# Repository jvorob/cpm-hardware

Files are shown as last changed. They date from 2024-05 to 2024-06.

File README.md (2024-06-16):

# cpm-hardware

This repo contains the design files for the custom PCB used in my Cathodic Protection Monitoring project.
These were developed in KiCad 8.
(see [main repo](https://github.com/jvorob/cpm-firmware) for more details)

`cpm_proj/` Contains the mk1 board used as of 2024.06.16, a 100x100mm 2-layer PCB.

`cpm_mk2/` is the start of a planned second version, if I get around to miniaturizing and deploying it.

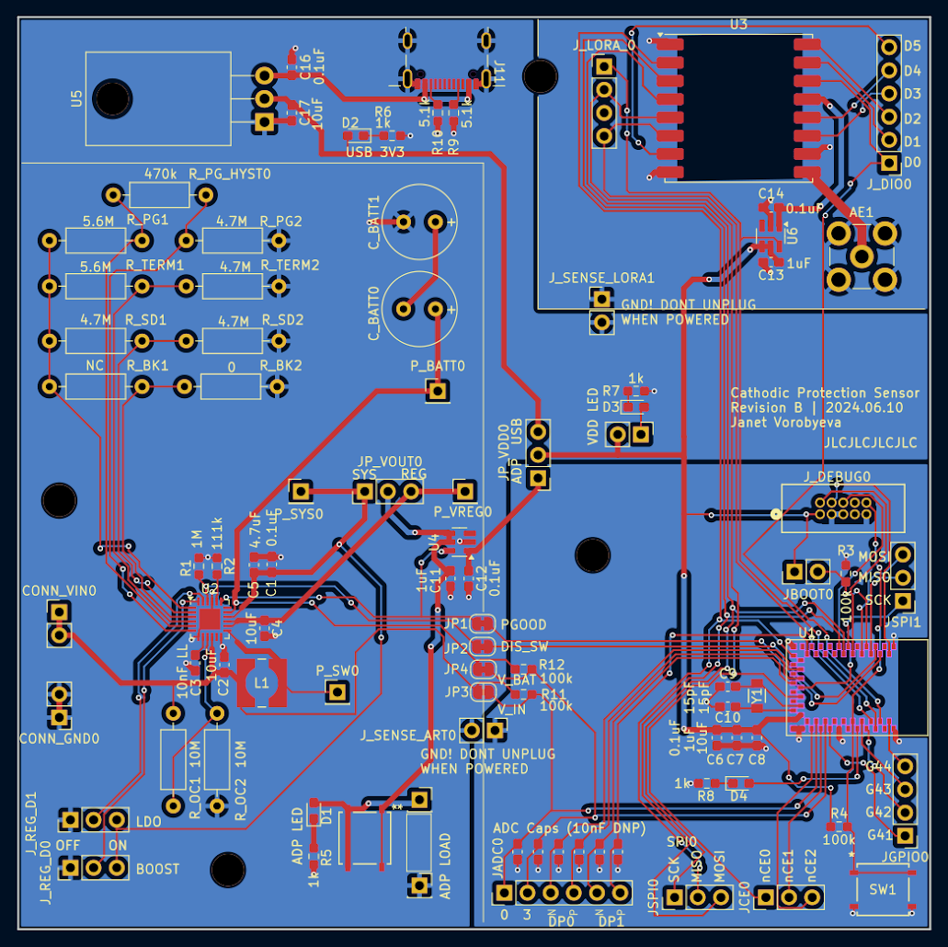
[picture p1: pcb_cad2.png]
Image of the mk1 pcb design


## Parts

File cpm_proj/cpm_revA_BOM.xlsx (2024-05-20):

Reference | Type | Value | Datasheet | Footprint | Qty | In Stock? | Order | DNP |  | PN | Digikey PN
C9,C10 | Passive – Capacitor | 15pF | ~ | Capacitor_SMD:C_0603_1608Metric_Pad1.08x0.95mm_HandSolder | 2 | ~30
C15,C18,C19,C20,C21,C22 | Passive – Capacitor | 1nF | ~ | Capacitor_SMD:C_0603_1608Metric_Pad1.08x0.95mm_HandSolder | 6 | ~30 |  | DNP
C1,C6,C12,C14,C16 | Passive – Capacitor | 0.1uF | ~ | Capacitor_SMD:C_0603_1608Metric_Pad1.08x0.95mm_HandSolder | 5 | ~20
C7,C11,C13 | Passive – Capacitor | 1uF | ~ | Capacitor_SMD:C_0603_1608Metric_Pad1.08x0.95mm_HandSolder | 3 | 30
C5 | Passive – Capacitor | 4.7uF | ~ | Capacitor_SMD:C_0603_1608Metric_Pad1.08x0.95mm_HandSolder | 1 | 0 | 50 |  | Jelly | C1608X5R1E475K080AC | 445-9050-1-ND
C2,C4,C8,C17 | Passive – Capacitor | 10uF | ~ | Capacitor_SMD:C_0603_1608Metric_Pad1.08x0.95mm_HandSolder | 4 | ~5
R11,R12,R3,R4 | Passive – Resistor | 100k | ~ | Resistor_SMD:R_0603_1608Metric_Pad0.98x0.95mm_HandSolder | 4 | ~20
R2 | Passive – Resistor | 111k | ~ | Resistor_SMD:R_0603_1608Metric_Pad0.98x0.95mm_HandSolder | 1 | ~20
R5,R6,R7,R8 | Passive – Resistor | 1k | ~ | Resistor_SMD:R_0603_1608Metric_Pad0.98x0.95mm_HandSolder | 4 | ~20 | 1000 |  | Jelly | RMCF0603FG1K00 | RMCF0603FG1K00CT-ND
R9,R10 | Passive – Resistor | 5.1k | ~ | Resistor_SMD:R_0603_1608Metric_Pad0.98x0.95mm_HandSolder | 2 | ~20
R1 | Passive – Resistor | 1M | ~ | Resistor_SMD:R_0603_1608Metric_Pad0.98x0.95mm_HandSolder | 1 | 0 | 50? |  | Jelly | RMCF0603FG1M00 | RMCF0603FG1M00CT-ND
R_OC1,R_OC2 | Passive – Resistor | 10M | ~ | Resistor_THT:R_Axial_DIN0207_L6.3mm_D2.5mm_P10.16mm_Horizontal | 2 | 8 | 0
R_PG1,R_TERM1 | Passive – Resistor | 5.6M | ~ | Resistor_THT:R_Axial_DIN0207_L6.3mm_D2.5mm_P10.16mm_Horizontal | 2 | 0 | 10 |  |  | CF14JT5M60 | CF14JT5M60CT-ND
R_PG2,R_SD1,R_SD2,R_TERM2 | Passive – Resistor | 4.7M | ~ | Resistor_THT:R_Axial_DIN0207_L6.3mm_D2.5mm_P10.16mm_Horizontal | 4 | 10 | 0
R_PG_HYST0 | Passive – Resistor | 470k | ~ | Resistor_THT:R_Axial_DIN0207_L6.3mm_D2.5mm_P10.16mm_Horizontal | 1 | 5 | 0
R_BK1 | N/A | NC | ~ | Resistor_THT:R_Axial_DIN0207_L6.3mm_D2.5mm_P10.16mm_Horizontal | 1 | N/A |  | DNP
R_BK2 | N/A | 0 | ~ | Resistor_THT:R_Axial_DIN0207_L6.3mm_D2.5mm_P10.16mm_Horizontal | 1 | N/A
C3 | Passive – Special | 10nF LL | https://www.digikey.com/en/products/detail/murata-electronics/GRT1885C1E103JA02J/13904823 | Capacitor_SMD:C_0603_1608Metric_Pad1.08x0.95mm_HandSolder | 1 | 0 | 10 |  |  | GRT1885C1E103JA02J | 490-GRT1885C1E103JA02JCT-ND
C_BATT0,C_BATT1 | Supercapacitor | 1F 2.7V | https://www.digikey.com/en/products/detail/cornell-dubilier-knowles/DGH105Q2R7/7387508 | Capacitor_THT:C_Radial_D8.0mm_H11.5mm_P3.50mm | 2 | 2 | 10 |  |  | DGH105Q2R7 | 338-DGH105Q2R7-ND
D1,D2,D3,D4 | Led | LED GN? | ~ | LED_SMD:LED_0603_1608Metric_Pad1.05x0.95mm_HandSolder | 4 | 0 | 20? |  | Jelly | SML-D12P8WT86 | 846-SML-D12P8WT86CT-ND
SW1, SW_ADP_LED0 | Switch | PTS526 Switch | https://www.digikey.com/en/products/detail/c-k/PTS526-SK15-SMTR2-LFS/10056626 | 0JV_CPM_Footprints:SMT_FS_PTS526 | 2 |  | 25 |  | Jelly | PTS526 SK15 SMTR2 LFS | CKN12221-1-ND
U1 | IC | Sparkfun Artemis | https://cdn.sparkfun.com/assets/learn_tutorials/9/0/9/Artemis_Integration_Guide.pdf | 0JV_CPM_Footprints:Sparkfun Artemis | 1 | 0 | 10? |  | Restock | WRL-15484 | 1568-WRL-15484CT-ND | 30c cheaper on sparkfun? | https://www.sparkfun.com/products/15484
U2 | IC | ADP5091 | https://www.analog.com/media/en/technical-documentation/data-sheets/ADP5091-5092.pdf | Package_CSP:LFCSP-24-1EP_4x4mm_P0.5mm_EP2.3x2.3mm | 1 | ??? | 2? |  |  | ADP5091ACPZ-1-R7 | 505-ADP5091ACPZ-1-R7CT-ND
U3 | IC | RFM95W-915S2 | https://www.hoperf.com/data/upload/portal/20181127/5bfcbea20e9ef.pdf | RF_Module:HOPERF_RFM9XW_SMD | 1 | ~2 | 0
U4,U6 | IC | TPS22860 | https://www.ti.com/lit/ds/symlink/tps22860.pdf | Package_TO_SOT_SMD:SOT-23-6 | 2 | 0 | 5? |  |  | TPS22860DBVR | 296-43982-1-ND
U5 | IC | LD1117AV33_TO220 | https://www.st.com/content/ccc/resource/technical/document/datasheet/a5/c3/3f/c9/2b/15/40/49/CD00002116.pdf/files/CD00002116.pdf/jcr:content/translations/en.C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 | Package_TO_SOT_THT:TO-220-3_Horizontal_TabDown | 1 | TRUE | 0
Y1 | Crystal | 32.768kHz | https://www.digikey.com/en/products/detail/ecs-inc/ECS-327-12-5-34B-TR/1693557 | 0JV_CPM_Footprints:XTAL_ECS-31B_ECS | 1 | 0 | 10 |  |  | ECS-.327-12.5-34B-TR | XC1617CT-ND
L1 | Inductor | 22uH | https://www.digikey.com/en/products/detail/w%C3%BCrth-elektronik/744042220/2931638 | 0JV_CPM_Footprints:IND_4818-WE-TPC_WRE | 1 | 0 | 10? |  |  | 744042220 | 732-3657-1-ND
J11 | Connector | USB_C_Receptacle_USB2.0 | https://www.digikey.com/en/products/detail/gct/USB4105-GF-A/11198441 | 0JV_CPM_Footprints:USB4105-GF-A | 1 | 0 | 10 |  | Jelly | USB4105-GF-A | 2073-USB4105-GF-ACT-ND
J_DEBUG0 | Connector | Conn_02x05_Odd_Even | https://www.digikey.com/en/products/detail/cnc-tech/3220-10-0100-00/3883661 | 0JV_CPM_Footprints:CONN_3220-10-0100-00_CNC | 1 | TRUE | 0 |  |  | 3220-10-0100-00 | 1175-1627-ND
AE1 | Connector | Antenna_Shield | https://app.adam-tech.com/products/download/data_sheet/219105/rf2-04a-t-00-50-g-data-sheet.pdf | 0JV_CPM_Footprints:SMB_Jack_Vertical_RF2 | 1 | TRUE | 0 |  |  |  | 2057-RF2-04A-T-00-50-G-ND
JADC0,J_DIO0 | JB Connector | Conn_01x06_Pin | ~ | Connector_PinHeader_2.54mm:PinHeader_1x06_P2.54mm_Vertical | 2 | TRUE
JCE0,JP_VDD0,JP_VOUT0,JSPI0,JSPI1,J_REG_D0,J_REG_D1 | JB Connector | Conn_01x03_Pin | ~ | Connector_PinHeader_2.54mm:PinHeader_1x03_P2.54mm_Vertical | 7 | TRUE
JGPIO0,J_LORA_0 | JB Connector | Conn_01x04_Pin | ~ | Connector_PinHeader_2.54mm:PinHeader_1x04_P2.54mm_Vertical | 2 | TRUE
J_LOAD0,J_LOAD1,P_SYS0,P_VREG0 | JB Connector | Conn_01x01_Socket | ~ | -- mixed values -- | 4 | TRUE
P_BATT0,P_SW0 | JB Connector | Conn_01x01_Pin | ~ | Connector_PinHeader_2.54mm:PinHeader_1x01_P2.54mm_Vertical | 2 | TRUE
CONN_GND0,CONN_VIN0,JBOOT0,J_SENSE_ART0,J_SENSE_LORA1,J_VDD_LED0 | JB Connector | Conn_01x02_Pin | ~ | Connector_PinHeader_2.54mm:PinHeader_1x02_P2.54mm_Vertical | 6 | TRUE
 |  | Big resistor kit? (100k-10Mohm, 0603) |  |  |  |  |  |  | (resistor kit) | KIT-RMCF0603JT-14
 |  | MEGOHM Resistors: | ( for kit-making |  |  | in stock | order?
 |  | 1 |  |  |  | 10
 |  | 1.5 |  |  |  | 0 | 10 |  | Misc 1-10Mohm THT resistors (filling gaps in our current stock)
 |  | 2.2 |  |  |  | 10
 |  | 3.3 |  |  |  | 0 | 10
 |  | 4.7 |  |  |  | 10
 |  | 6.8 |  |  |  |  | 10
 |  | 10 |  |  |  | 10

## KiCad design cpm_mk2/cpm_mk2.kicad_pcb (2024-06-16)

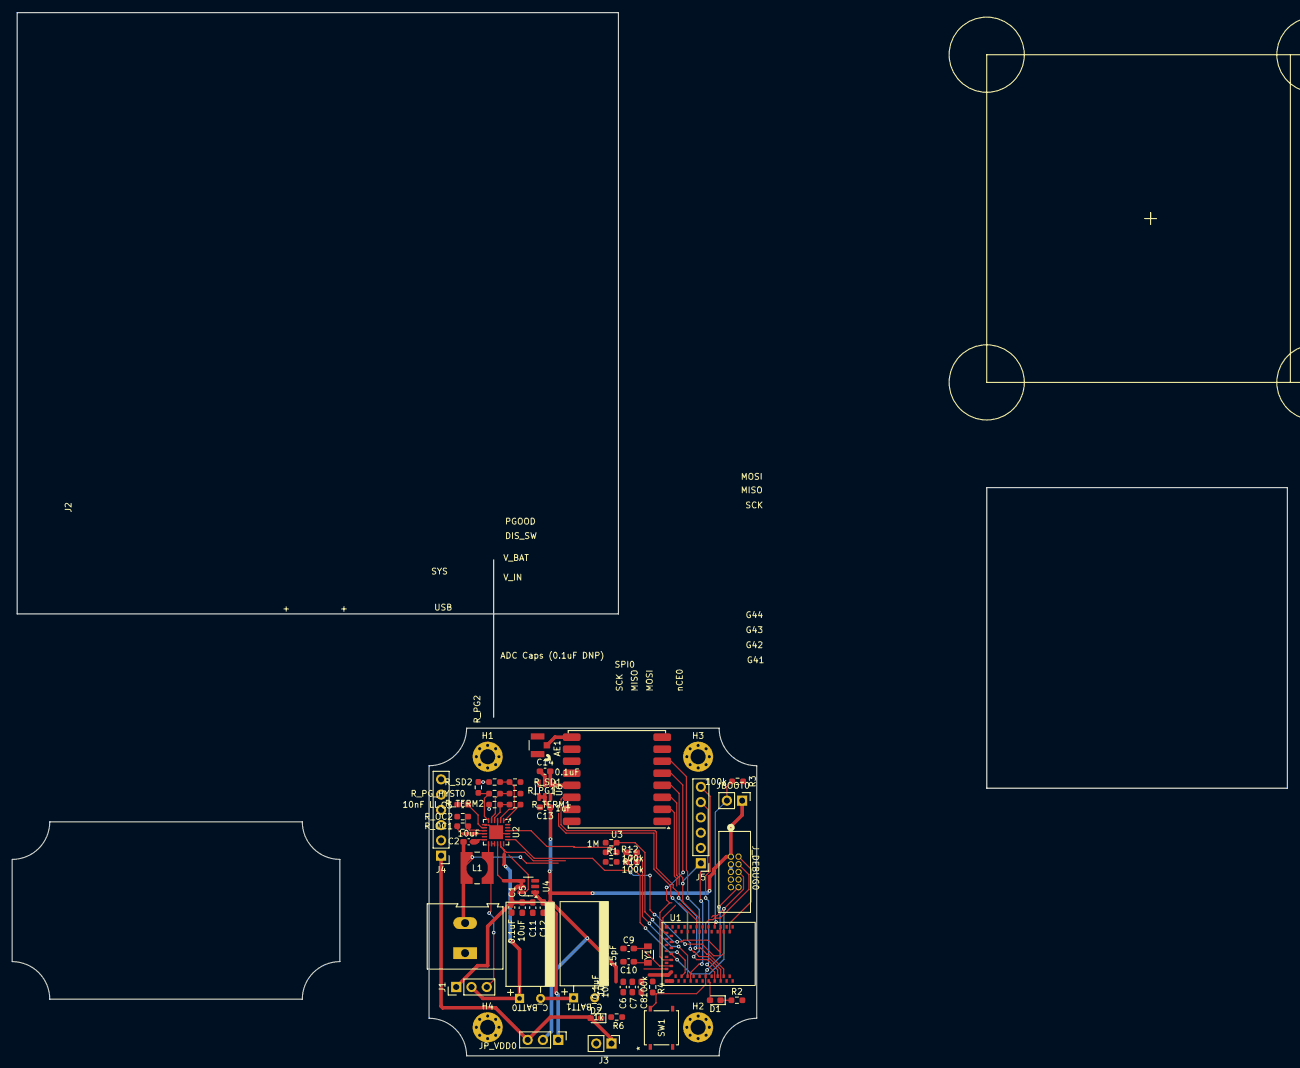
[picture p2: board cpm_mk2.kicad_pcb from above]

Board: 2 copper layers, 54.5 x 54.5 mm, 56 parts (0 on the bottom side), 42 nets.

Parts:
AE1: Antenna_Shield; CONN1_CONUFL_TEC
C1, C6, C12, C14: 0.1uF; C_0603_1608Metric_Pad1.08x0.95mm_HandSolder
C2, C5, C8: 10uF; C_0603_1608Metric_Pad1.08x0.95mm_HandSolder
C3: 10nF LL; C_0603_1608Metric_Pad1.08x0.95mm_HandSolder
C7, C11, C13: 1uF; C_0603_1608Metric_Pad1.08x0.95mm_HandSolder
C9, C10: 15pF; C_0603_1608Metric_Pad1.08x0.95mm_HandSolder
C15, C22: 1nF; C_0603_1608Metric_Pad1.08x0.95mm_HandSolder
C_BATT0, C_BATT1: 1F 2.7V; DGH105Q2R7
D1, D2: LED; LED_0603_1608Metric_Pad1.05x0.95mm_HandSolder
H1, H2, H3, H4: MountingHole_Pad; MountingHole_2.5mm_Pad_Via
J1: Conn_01x03_Pin; PinHeader_1x03_P2.54mm_Vertical
J2: Screw_Terminal_01x02; TerminalBlock_Altech_AK300-2_P5.00mm
J3: Conn_01x02_Pin; PinHeader_1x02_P2.54mm_Vertical
J4, J5: Conn_01x06_Pin; PinHeader_1x06_P2.54mm_Vertical
JBOOT0: Conn_01x02_Pin; PinHeader_1x02_P2.54mm_Vertical
JP_VDD0: Conn_01x03_Pin; PinHeader_1x03_P2.54mm_Vertical
J_DEBUG0: Conn_02x05_Odd_Even; CONN_3220-10-0100-00_CNC
L1: 22uH; IND_4818-WE-TPC_WRE
R1: 1M; R_0603_1608Metric_Pad0.98x0.95mm_HandSolder
R2, R6: 1k; R_0603_1608Metric_Pad0.98x0.95mm_HandSolder
R3, R4, R11, R12: 100k; R_0603_1608Metric_Pad0.98x0.95mm_HandSolder
R_OC1, R_OC2: 10M; R_0603_1608Metric_Pad0.98x0.95mm_HandSolder
R_PG1: 5.6M; R_0603_1608Metric_Pad0.98x0.95mm_HandSolder
R_PG2: 4.7M; R_0603_1608Metric_Pad0.98x0.95mm_HandSolder
R_PG_HYST0: 470k; R_0603_1608Metric_Pad0.98x0.95mm_HandSolder
R_SD1, R_SD2: 4.7M; R_0603_1608Metric_Pad0.98x0.95mm_HandSolder
R_TERM1: 5.6M; R_0603_1608Metric_Pad0.98x0.95mm_HandSolder
R_TERM2: 4.7M; R_0603_1608Metric_Pad0.98x0.95mm_HandSolder
SW1: RESET; SMT_FS_PTS526
U1: Sparkfun Artemis
U2: ADP5091; LFCSP-24-1EP_4x4mm_P0.5mm_EP2.3x2.3mm
U3: RFM95W-915S2; HOPERF_RFM9XW_SMD
U4, U6: TPS22860; SOT-23-6
Y1: 32.768kHz; XTAL_ECS-31B_ECS

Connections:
/SPI0.MISO: J5.2, U1.23 (GPIO6), U3.2 (MISO)
/SPI0.MOSI: J5.3, U1.13 (GPIO7), U3.3 (MOSI)
/SPI0.SCK: J5.1, U1.12 (GPIO5), U3.4 (SCK)
/SPI0.nCE0: J5.4, U1.32 (GPIO11), U3.5 (NSS)
/VADP_{IN}: C2.1, J2.2, J4.3, L1.2, R11.1, R_OC1.1, U2.10 (VIN)
/VADP_{OUT}: C1.1, C5.1, C11.1, J1.1, U2.16 (SYS), U4.4 (V_{IN}), U4.5 (V_{BIAS})
/VIN_{3V3}: D2.2 (A), J3.1, J4.1, JP_VDD0.3
/artemis/ADC0/TRIG0/CMPIN0: C15.2, R11.2, U1.42 (GPIO16)
/artemis/ADC3: C22.2, R12.2, U1.44 (GPIO31)
/artemis/BOOT: JBOOT0.2, R3.1, U1.7 (GPIO47/BOOT)
/artemis/DIS_SW: R1.1, U1.5 (GPIO40), U2.22 (DIS_SW)
/artemis/LED: D1.2 (A), U1.51 (GPIO0)
/artemis/LORA_EN: U1.55 (GPIO36), U6.6 (ON)
/artemis/LORA_RST: U1.54 (GPIO3), U3.6 (RESET)
/artemis/LORA_T/RXDONE: U1.56 (GPIO38), U3.14 (DIO0)
/artemis/MISC_GPIO_0: J5.5, U1.45 (GPIO41)
/artemis/MISC_GPIO_1: J5.6, U1.53 (GPIO42)
/artemis/PWR_GOOD: U1.4 (GPIO39), U2.19 (PGOOD), U4.6 (ON)
/artemis/SWDCK: J_DEBUG0.2, U1.2 (GPIO20/SWDCK)
/artemis/SWDIO: J_DEBUG0.4, U1.10 (GPIO21/SWDIO)
/artemis/SWO: J_DEBUG0.6, U1.30 (GPIO33)
/artemis/nRESET: J_DEBUG0.10, R4.2, SW1.1, SW1.2, U1.50 (nRESET)
/lora/V33_{LORA}: C14.1, U3.13 (3.3V), U6.1 (V_{OUT})
/power/SW: J1.3, L1.1, U2.13 (SW)
/power/V_BAT: C_BATT0.1 (+), J1.2, R12.1, U2.17 (BAT)
GND: AE1.2 (Shield), C1.2, C2.2, C3.1, C5.2, C6.2, C7.2, C8.2, C9.2, C10.2, C11.2, C12.2, C13.2, C14.2, C15.1, C22.1, C_BATT1.2 (-), H1.1, H2.1, H3.1, H4.1, J2.1, J3.2, J4.4, J4.5, J4.6, J_DEBUG0.3, J_DEBUG0.5, J_DEBUG0.9, R1.2, R2.2, R3.2, R6.2, R_OC2.2, R_PG2.2, R_SD2.2, R_TERM2.2, SW1.3 (K), SW1.4 (A), U1.1 (GND), U1.22 (GND), U1.38 (GND), U1.39 (GND), U1.47 (GND), U1.59 (GND), U2.3 (SETBK), U2.7 (AGND), U2.12 (PGND), U2.20 (VID), U2.21 (MINOP), U2.23 (REG_D1), U2.24 (REG_D0), U2.25 (AGND), U3.1 (GND), U3.8 (GND), U3.10 (GND), U4.2 (GND), U6.2 (GND)
unnamed: AE1.1 (A), U3.9 (ANT)
unnamed: C_BATT0.2 (-), C_BATT1.1 (+)
unnamed: D1.1 (K), R2.1
unnamed: D2.1 (K), R6.1
unnamed: C12.1, JP_VDD0.1, U4.1 (V_{OUT})
unnamed: C10.1, U1.35 (XI), Y1.1
unnamed: C9.1, U1.34 (XO), Y1.2
unnamed: C3.2, U2.8 (CBP)
unnamed: R_OC1.2, R_OC2.1, U2.9 (MPPT)
unnamed: R_PG1.1, R_SD1.1, R_TERM1.1, U2.1 (REF)
unnamed: U2.14 (REG_OUT), U2.15 (REG_FB)
unnamed: R_PG2.1, R_PG_HYST0.2, U2.6 (SETHYST)
unnamed: R_PG1.2, R_PG_HYST0.1, U2.5 (SETPG)
unnamed: R_SD1.2, R_SD2.1, U2.2 (SETSD)
unnamed: R_TERM1.2, R_TERM2.1, U2.4 (TERM)
VDD: C6.1, C7.1, C8.1, C13.1, J4.2, JBOOT0.1, JP_VDD0.2, J_DEBUG0.1, R4.1, U1.36 (VDD), U1.37 (VDD), U6.4 (V_{IN}), U6.5 (V_{BIAS})

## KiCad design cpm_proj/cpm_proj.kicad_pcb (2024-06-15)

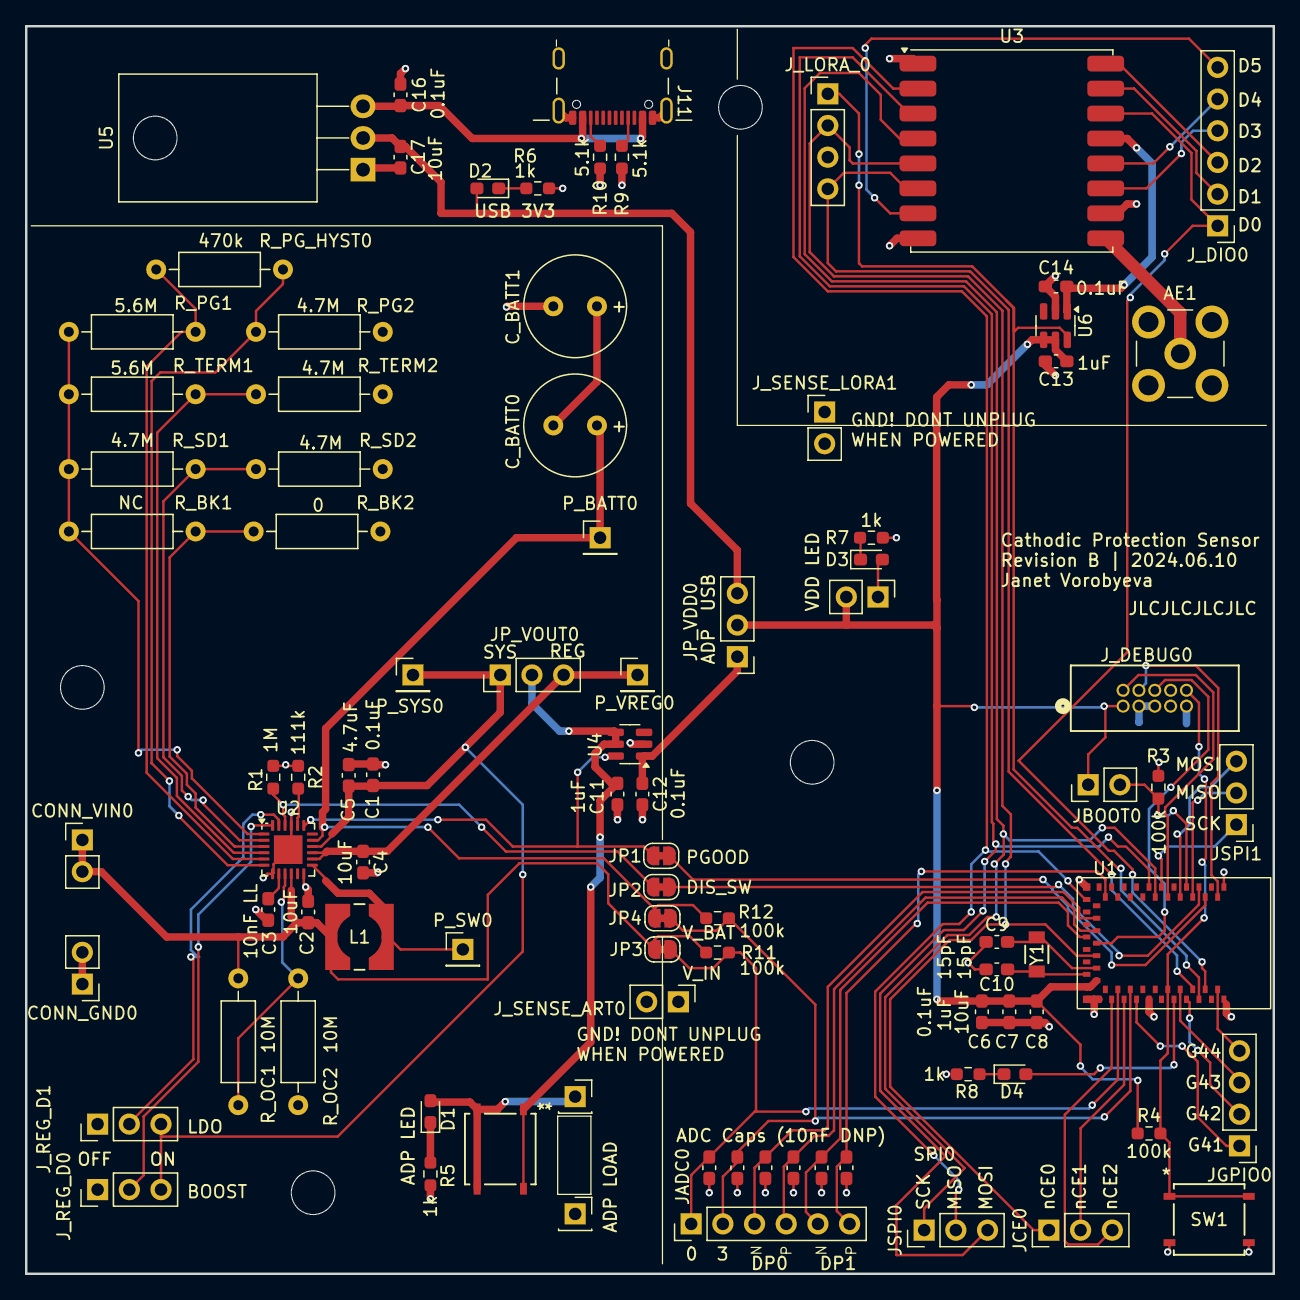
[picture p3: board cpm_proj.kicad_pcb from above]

Board: 2 copper layers, 100.0 x 100.0 mm, 95 parts (0 on the bottom side), 74 nets.

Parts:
AE1: Antenna_Shield; SMB_Jack_Vertical_RF2
C1, C6, C12, C14, C16: 0.1uF; C_0603_1608Metric_Pad1.08x0.95mm_HandSolder
C2, C4, C8, C17: 10uF; C_0603_1608Metric_Pad1.08x0.95mm_HandSolder
C3: 10nF LL; C_0603_1608Metric_Pad1.08x0.95mm_HandSolder
C5: 4.7uF; C_0603_1608Metric_Pad1.08x0.95mm_HandSolder
C7, C11, C13: 1uF; C_0603_1608Metric_Pad1.08x0.95mm_HandSolder
C9, C10: 15pF; C_0603_1608Metric_Pad1.08x0.95mm_HandSolder
C15, C18, C19, C20, C21, C22: 1nF; C_0603_1608Metric_Pad1.08x0.95mm_HandSolder
CONN_GND0: Conn_01x02_Pin; PinHeader_1x02_P2.54mm_Vertical
CONN_VIN0: Conn_01x02_Pin; PinHeader_1x02_P2.54mm_Vertical
C_BATT0, C_BATT1: 1F 2.7V; C_Radial_D8.0mm_H11.5mm_P3.50mm
D1, D2, D3, D4: LED; LED_0603_1608Metric_Pad1.05x0.95mm_HandSolder
H1, H2, H3, H4: MountingHole; MountingHole_3.5mm
J11: USB_C_Receptacle_USB2.0; USB4105-GF-A
JADC0: Conn_01x06_Pin; PinHeader_1x06_P2.54mm_Vertical
JBOOT0: Conn_01x02_Pin; PinHeader_1x02_P2.54mm_Vertical
JCE0: Conn_01x03_Pin; PinHeader_1x03_P2.54mm_Vertical
JGPIO0: Conn_01x04_Pin; PinHeader_1x04_P2.54mm_Vertical
JP1, JP2, JP3, JP4: SolderJumper_2_Bridged; SolderJumper-2_P1.3mm_Bridged_RoundedPad1.0x1.5mm
JP_VDD0: Conn_01x03_Pin; PinHeader_1x03_P2.54mm_Vertical
JP_VOUT0: Conn_01x03_Pin; PinHeader_1x03_P2.54mm_Vertical
JSPI0, JSPI1: Conn_01x03_Pin; PinHeader_1x03_P2.54mm_Vertical
J_DEBUG0: Conn_02x05_Odd_Even; CONN_3220-10-0100-00_CNC
J_DIO0: Conn_01x06_Pin; PinHeader_1x06_P2.54mm_Vertical
J_LOAD0, J_LOAD1: Conn_01x01_Socket; PinSocket_1x01_P2.54mm_Vertical
J_LORA_0: Conn_01x04_Pin; PinHeader_1x04_P2.54mm_Vertical
J_REG_D0, J_REG_D1: Conn_01x03_Pin; PinHeader_1x03_P2.54mm_Vertical
J_SENSE_ART0: Conn_01x02_Pin; PinHeader_1x02_P2.54mm_Vertical
J_SENSE_LORA1: Conn_01x02_Pin; PinHeader_1x02_P2.54mm_Vertical
J_VDD_LED0: Conn_01x02_Pin; PinHeader_1x02_P2.54mm_Vertical
L1: 22uH; IND_4818-WE-TPC_WRE
P_BATT0: Conn_01x01_Pin; PinHeader_1x01_P2.54mm_Vertical
P_SW0: Conn_01x01_Pin; PinHeader_1x01_P2.54mm_Vertical
P_SYS0: Conn_01x01_Socket; PinHeader_1x01_P2.54mm_Vertical
P_VREG0: Conn_01x01_Socket; PinHeader_1x01_P2.54mm_Vertical
R1: 1M; R_0603_1608Metric_Pad0.98x0.95mm_HandSolder
R2: 111k; R_0603_1608Metric_Pad0.98x0.95mm_HandSolder
R3, R4, R11, R12: 100k; R_0603_1608Metric_Pad0.98x0.95mm_HandSolder
R5, R6, R7, R8: 1k; R_0603_1608Metric_Pad0.98x0.95mm_HandSolder
R9, R10: 5.1k; R_0603_1608Metric_Pad0.98x0.95mm_HandSolder
R_BK1: NC; R_Axial_DIN0207_L6.3mm_D2.5mm_P10.16mm_Horizontal
R_BK2: 0; R_Axial_DIN0207_L6.3mm_D2.5mm_P10.16mm_Horizontal
R_OC1, R_OC2: 10M; R_Axial_DIN0207_L6.3mm_D2.5mm_P10.16mm_Horizontal
R_PG1: 5.6M; R_Axial_DIN0207_L6.3mm_D2.5mm_P10.16mm_Horizontal
R_PG2: 4.7M; R_Axial_DIN0207_L6.3mm_D2.5mm_P10.16mm_Horizontal
R_PG_HYST0: 470k; R_Axial_DIN0207_L6.3mm_D2.5mm_P10.16mm_Horizontal
R_SD1, R_SD2: 4.7M; R_Axial_DIN0207_L6.3mm_D2.5mm_P10.16mm_Horizontal
R_TERM1: 5.6M; R_Axial_DIN0207_L6.3mm_D2.5mm_P10.16mm_Horizontal
R_TERM2: 4.7M; R_Axial_DIN0207_L6.3mm_D2.5mm_P10.16mm_Horizontal
SW1: RESET; SMT_FS_PTS526
SW_ADP_LED0: ADP_LED; SMT_FS_PTS526
U1: Sparkfun Artemis
U2: ADP5091; LFCSP-24-1EP_4x4mm_P0.5mm_EP2.3x2.3mm
U3: RFM95W-915S2; HOPERF_RFM9XW_SMD
U4, U6: TPS22860; SOT-23-6
U5: LD1117AV33_TO220; TO-220-3_Horizontal_TabDown
Y1: 32.768kHz; XTAL_ECS-31B_ECS

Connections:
/SPI0.MISO: JSPI0.2, U1.23 (GPIO6), U3.2 (MISO)
/SPI0.MOSI: JSPI0.3, U1.13 (GPIO7), U3.3 (MOSI)
/SPI0.SCK: JSPI0.1, U1.12 (GPIO5), U3.4 (SCK)
/SPI0.nCE0: JCE0.1, J_LORA_0.2, U1.32 (GPIO11), U3.5 (NSS)
/SPI0.nCE1: JCE0.2, U1.43 (GPIO17)
/SPI0.nCE2: JCE0.3, U1.41 (GPIO18)
/VADP_{IN}: C2.1, CONN_VIN0.1, CONN_VIN0.2, JP3.1 (A), L1.2, R11.1, R_OC1.1, U2.10 (VIN)
/VADP_{OUT}: C11.1, JP_VOUT0.2, SW_ADP_LED0.1, SW_ADP_LED0.2, U4.4 (V_{IN}), U4.5 (V_{BIAS})
/VUSB_{3V3}: C17.1, D2.2 (A), JP_VDD0.3, U5.2 (VO)
/VUSB_{5V}: C16.1, J11.A4/B9 (VBUS), J11.A9/B4 (VBUS), U5.3 (VI)
/artemis/ADC0/TRIG0/CMPIN0: C15.2, JADC0.1, JP3.2 (B), R11.2, U1.42 (GPIO16)
/artemis/ADC3: C22.2, JADC0.2, JP4.2 (B), R12.2, U1.44 (GPIO31)
/artemis/ADC_DP0_{N}: C18.2, JADC0.3, U1.26 (GPIO12)
/artemis/ADC_DP0_{P}: C19.2, JADC0.4, U1.28 (GPIO13)
/artemis/ADC_DP1_{N}: C20.2, JADC0.5, U1.29 (GPIO15)
/artemis/ADC_DP1_{P}: C21.2, JADC0.6, U1.20 (GPIO14)
/artemis/BOOT: JBOOT0.2, R3.1, U1.7 (GPIO47/BOOT)
/artemis/DIS_SW: JP2.2 (B), U1.5 (GPIO40)
/artemis/GND_{ARTEMIS}: C6.2, C7.2, C8.2, C9.2, C10.2, C15.1, C18.1, C19.1, C20.1, C21.1, C22.1, J_DEBUG0.3, J_DEBUG0.5, J_DEBUG0.9, J_SENSE_ART0.1, R3.2, R8.2, SW1.3 (K), SW1.4 (A), U1.1 (GND), U1.22 (GND), U1.38 (GND), U1.39 (GND), U1.47 (GND), U1.59 (GND)
/artemis/LED: D4.2 (A), U1.51 (GPIO0)
/artemis/LORA_EN: J_LORA_0.1, U1.55 (GPIO36), U6.6 (ON)
/artemis/LORA_T/RXDONE: J_DIO0.1, U1.56 (GPIO38), U3.14 (DIO0)
/artemis/LORA_nRST: J_LORA_0.4, U1.54 (GPIO3), U3.6 (nRESET)
/artemis/MISC_GPIO_0: JGPIO0.1, U1.45 (GPIO41)
/artemis/MISC_GPIO_1: JGPIO0.2, U1.53 (GPIO42)
/artemis/MISC_GPIO_2: JGPIO0.3, U1.52 (GPIO43)
/artemis/MISC_GPIO_3: JGPIO0.4, U1.58 (GPIO44)
/artemis/PWR_GOOD: JP1.2 (B), U1.4 (GPIO39)
/artemis/SPI1.MISO: JSPI1.2, U1.6 (GPIO9)
/artemis/SPI1.MOSI: JSPI1.3, U1.8 (GPIO10)
/artemis/SPI1.SCK: JSPI1.1, U1.11 (GPIO8)
/artemis/SWDCK: J_DEBUG0.4, U1.2 (GPIO20/SWDCK)
/artemis/SWDIO: J_DEBUG0.2, U1.10 (GPIO21/SWDIO)
/artemis/SWO: J_DEBUG0.6, U1.30 (GPIO33)
/artemis/nRESET: J_DEBUG0.10, R4.2, SW1.1, SW1.2, U1.50 (nRESET)
/lora/GND_LORA_SENSE: AE1.2 (Shield), C13.2, C14.2, J_SENSE_LORA1.1, U3.1 (GND), U3.8 (GND), U3.10 (GND), U6.2 (GND)
/lora/V33_{LORA}: C14.1, U3.13 (3.3V), U6.1 (V_{OUT})
/power/BAT: C_BATT0.1 (+), JP4.1 (A), P_BATT0.1, R12.1, U2.17 (BAT)
/power/DIS_SW: JP2.1 (A), R1.1, U2.22 (DIS_SW)
/power/PGOOD: JP1.1 (A), U2.19 (PGOOD), U4.6 (ON)
/power/REG_D0: J_REG_D0.2, U2.24 (REG_D0)
/power/REG_D1: J_REG_D1.2, U2.23 (REG_D1)
/power/SW: L1.1, P_SW0.1, U2.13 (SW)
/power/VID: R2.1, U2.20 (VID)
/power/V_REG: C4.1, JP_VOUT0.3, P_VREG0.1, U2.14 (REG_OUT), U2.15 (REG_FB)
/power/V_SYS: C1.1, C5.1, JP_VOUT0.1, J_REG_D0.3, J_REG_D1.3, P_SYS0.1, U2.16 (SYS)
GND: C1.2, C2.2, C3.1, C4.2, C5.2, C11.2, C12.2, C16.2, C17.2, CONN_GND0.1, CONN_GND0.2, C_BATT1.2 (-), J11.A1/B12 (GND), J11.A12/B1 (GND), J11.S1 (SHIELD), J_LOAD1.1, J_REG_D0.1, J_REG_D1.1, J_SENSE_ART0.2, J_SENSE_LORA1.2, R1.2, R2.2, R5.2, R6.2, R7.2, R9.2, R10.2, R_BK2.2, R_OC2.2, R_PG2.2, R_SD2.2, R_TERM2.2, U2.7 (AGND), U2.12 (PGND), U2.21 (MINOP), U2.25 (AGND), U4.2 (GND), U5.1 (GND)
unnamed: AE1.1 (A), U3.9 (ANT)
unnamed: C_BATT0.2 (-), C_BATT1.1 (+)
unnamed: D1.2 (A), J_LOAD0.1, SW_ADP_LED0.3 (K), SW_ADP_LED0.4 (A)
unnamed: D1.1 (K), R5.1
unnamed: D2.1 (K), R6.1
unnamed: D3.2 (A), J_VDD_LED0.1
unnamed: D3.1 (K), R7.1
unnamed: D4.1 (K), R8.1
unnamed: J11.A5 (CC1), R9.1
unnamed: J11.B5 (CC2), R10.1
unnamed: C12.1, JP_VDD0.1, U4.1 (V_{OUT})
unnamed: J_DIO0.2, U3.15 (DIO1)
unnamed: J_DIO0.3, U3.16 (DIO2)
unnamed: J_DIO0.4, U3.11 (DIO3)
unnamed: J_DIO0.5, U3.12 (DIO4)
unnamed: J_DIO0.6, U3.7 (DIO5)
unnamed: C10.1, U1.35 (XI), Y1.1
unnamed: C9.1, U1.34 (XO), Y1.2
unnamed: C3.2, U2.8 (CBP)
unnamed: R_OC1.2, R_OC2.1, U2.9 (MPPT)
unnamed: R_BK1.1, R_PG1.1, R_SD1.1, R_TERM1.1, U2.1 (REF)
unnamed: R_BK1.2, R_BK2.1, U2.3 (SETBK)
unnamed: R_PG2.1, R_PG_HYST0.2, U2.6 (SETHYST)
unnamed: R_PG1.2, R_PG_HYST0.1, U2.5 (SETPG)
unnamed: R_SD1.2, R_SD2.1, U2.2 (SETSD)
unnamed: R_TERM1.2, R_TERM2.1, U2.4 (TERM)
VDD: C6.1, C7.1, C8.1, C13.1, JBOOT0.1, JP_VDD0.2, J_DEBUG0.1, J_VDD_LED0.2, R4.1, U1.36 (VDD), U1.37 (VDD), U6.4 (V_{IN}), U6.5 (V_{BIAS})

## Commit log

2024-05-20 rev A (first pcb order)
    [artemis.kicad_sch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]
2024-06-11 Revision B
    Fixed SWDIO/SWDCK
    Relabeled ADC Caps to 10nF
    Relabelled LORA reset line to active low
    Minor silkscreen tweaks
    [artemis.kicad_sch, cpm_proj.kicad_pcb, cpm_proj.kicad_sch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]
2024-06-15 Removed bonus JLCJLC text
    [cpm_proj.kicad_pcb]
2024-06-16 Moved everything one directory deeper
    [artemis.kicad_sch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]
2024-06-16 Added cpm_mk2 repo
    [artemis.kicad_sch, cpm_mk2.kicad_pcb, cpm_mk2.kicad_sch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]
